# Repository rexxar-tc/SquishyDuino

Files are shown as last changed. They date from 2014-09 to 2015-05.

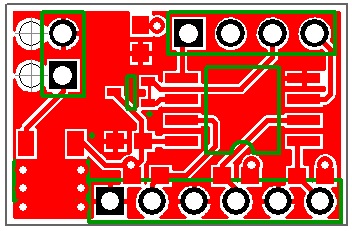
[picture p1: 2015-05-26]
Hardware/PCB_Top.jpg

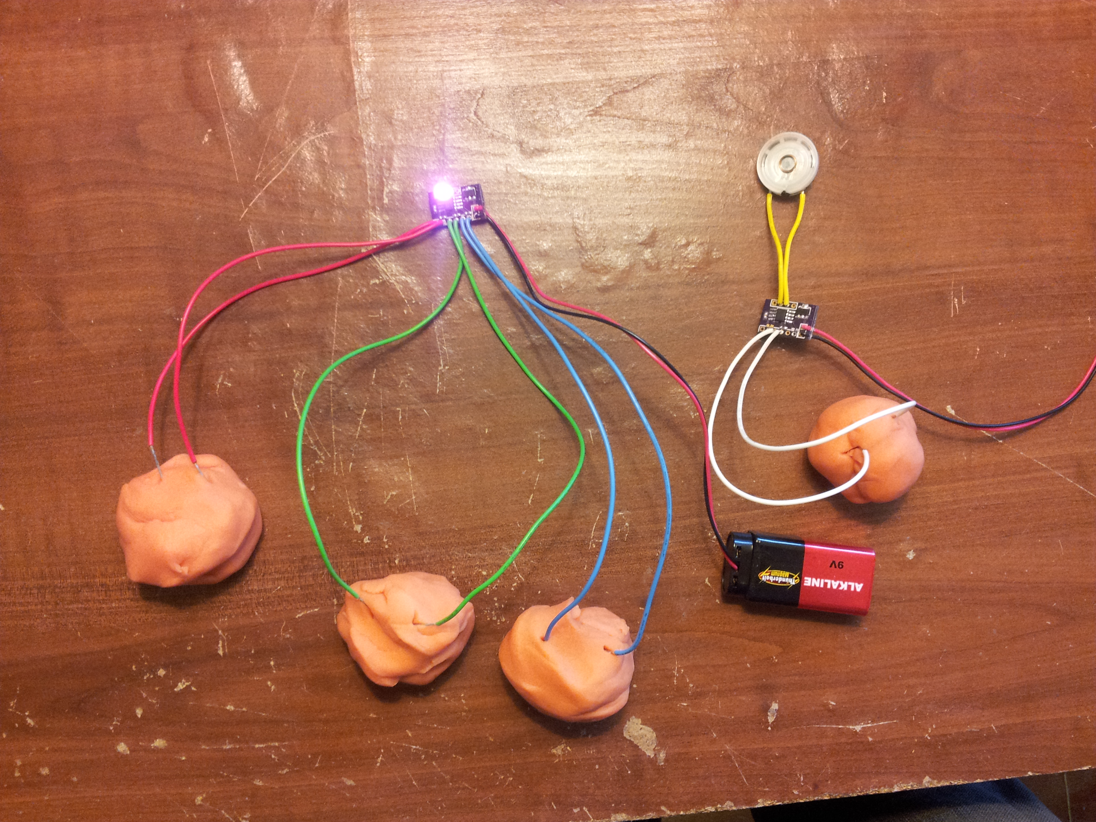
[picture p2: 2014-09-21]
SquishyDuino.jpg

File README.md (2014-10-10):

SquishyDuino
============

##About SquishyDuino

This project came about as part of a children's program at my public library with [Squishy Circuits](http://squishycircuitsstore.com). The hardware is as small and cheap as reasonably possible, and so far has survived abuse by groups of 30+ 8-10 year olds.

The code is inspired by code from St. Thomas University, who created Squishy Circuts. We had to completely re-write it for the ATtiny, but they still get credit for the idea.

The ATtiny25 is not *oficially* supported by Arduino, but we used the [arduino-tiny](https://code.google.com/p/arduino-tiny/) core which worked pretty well.

Essentially, Squishy Circuits is a type of play-dough that has reasonably good conductivity. You can stick an ADC across a lump of dough, and the read voltage will change as the kids play with the dough. Here, we used the ADC values to vary the tone of a speaker, or the individual colors of an RGB LED.

##Tindie Store

SquishyDuino is now available on my [tindie store!](https://www.tindie.com/stores/rexxar/)

Rev2 addresses a problem I didn't expect in the original design; The ATtiny can't source much current, so the speaker was very, very quiet. I fixed that, and updated the code to make it sound better.

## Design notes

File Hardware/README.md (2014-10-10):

##Hardware
==========

The hardware is very simple, but it does use small 0603 surface mount parts, so it will take at least a good temperature-controlled soldering iron to put together.

###Bill of Materials

This is a very short list:

- ATTiny25 in SO-8 package
- 1 1 uf ceramic capacitor in 0603 package
- 1 L7805 5V regulator in SOT89 package
- 1 9V battery clip
- Several pieces of wire

In addition, the LED version requires
- 4 470 ohm resistors in 0603 package
- 1 Common-cathode RGB LED

The buzzer version requires
- 1 small mylar speaker
- 1 220 and 1 470 ohm resistors
- 1 BC846 NPN transistor in SOT-323 package

I recommend [Mouser.com](http://mouser.com) or [Digikey.com](digikey.com) for sourcing these parts.

###PCB

I develop in DipTrace, so I've uploaded both the .dip and gerber files for you to make your own boards, and the boards are also available at [OSHPark](https://oshpark.com/shared_projects/PD8c1KSo) ready to order. 

##Assembly

Assembly requires you be familiar with surface-mount soldering techniques.

The transistor is used as a crude amplifier for the buzzer version, and should not be placed for the LED version. There is a small trace bridging two of the pads of the transistor. If you're building the buzzer version, cut this trace with a razor. For the buzzer, you need to place a 220 ohm resistor in the spot above the transistor, and a 470 ohm resistor on the center placement on the input row. You only need to place wires on the center two pins of the input row, and the speaker goes on the center two pins on the output.

For the LED, leave the bridging trace alone, and don't populate the transistor, then place 470 ohm resistors everywhere else. The LED pinout should be red, ground, green, blue, from left to right. The input wires follow the same order.

Before assembly, make sure to read the Software documentation, as programming the chip is not entirely straightforward.

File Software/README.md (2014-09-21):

##Software
==========

Here's both the Arduino files and pre-compiled hex files ready for uploading. You will need some type of ISP programmer to upload the code. I use an Arduino Leonardo as a programmer. It's easiest to do this with the ATTiny on the board, with only the capacitor and voltage regulator.

The programming pins are

- RESET - 1
- MOSI  - 5
- MISO  - 6
- SCK   - 7

You also need to program the fuses to disable the reset line, as it's used as one of the ADC inputs.

Fuses should be set to

- Low      0xE2
- High	   0x77
- Extended 0xFF

If for some reason you need to reprogram, you'll have to remove the ATTiny and use a high-voltage serial programmer.

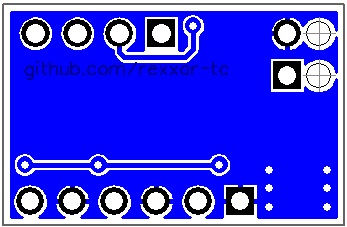
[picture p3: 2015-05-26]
Hardware/PCB_Bottom.jpg

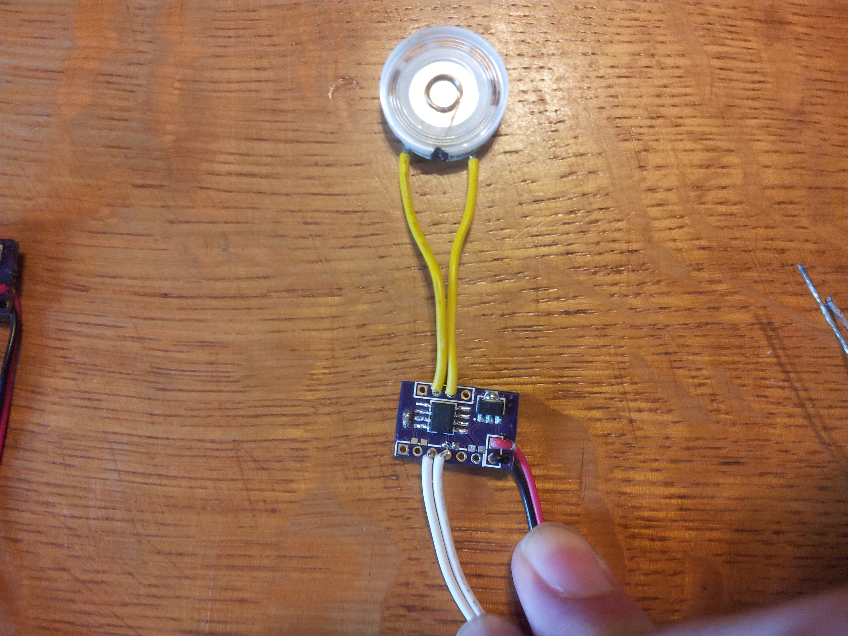
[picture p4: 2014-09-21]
Squishy_Buzzer.jpg

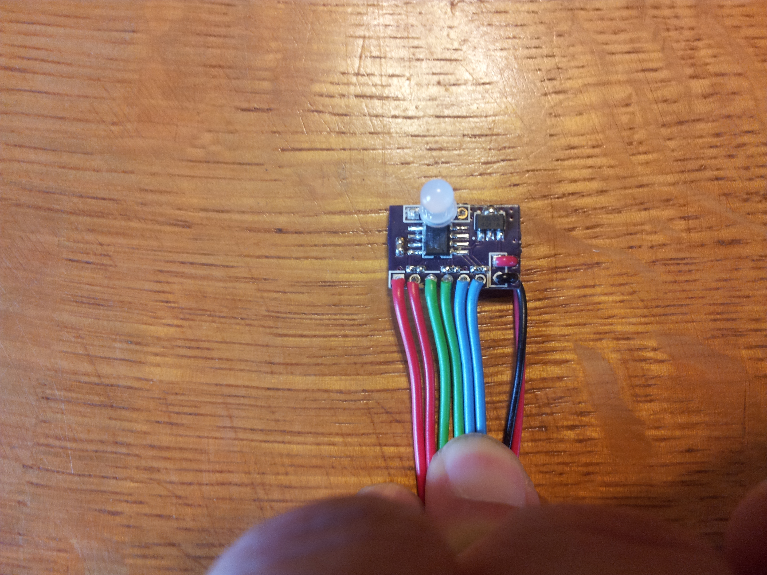
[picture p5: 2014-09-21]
Squishy_RGB.jpg

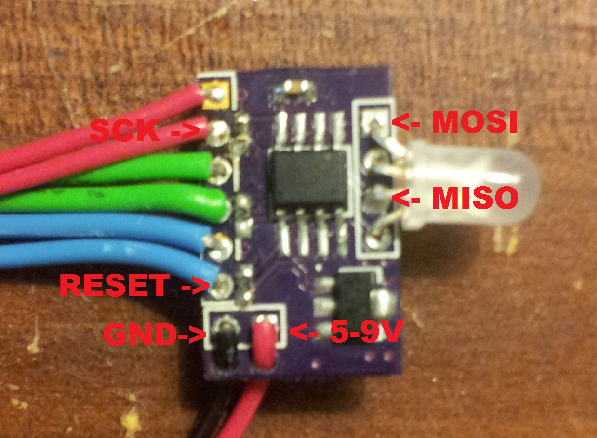
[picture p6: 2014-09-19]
Software/SPI pins.png

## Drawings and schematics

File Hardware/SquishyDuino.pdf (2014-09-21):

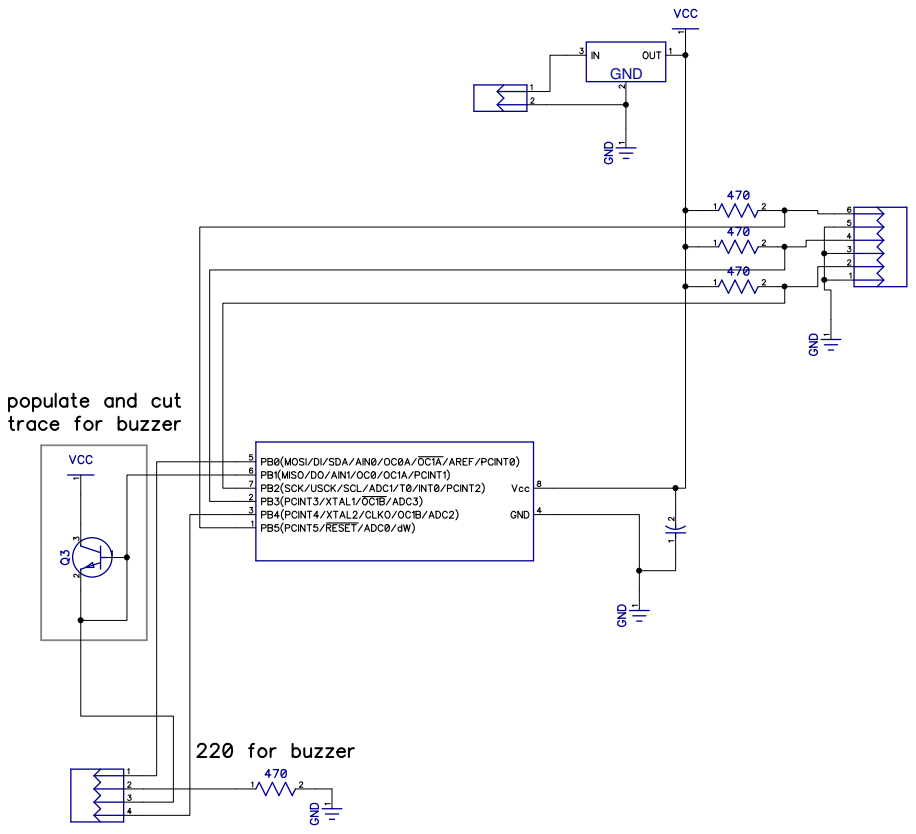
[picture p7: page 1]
GND

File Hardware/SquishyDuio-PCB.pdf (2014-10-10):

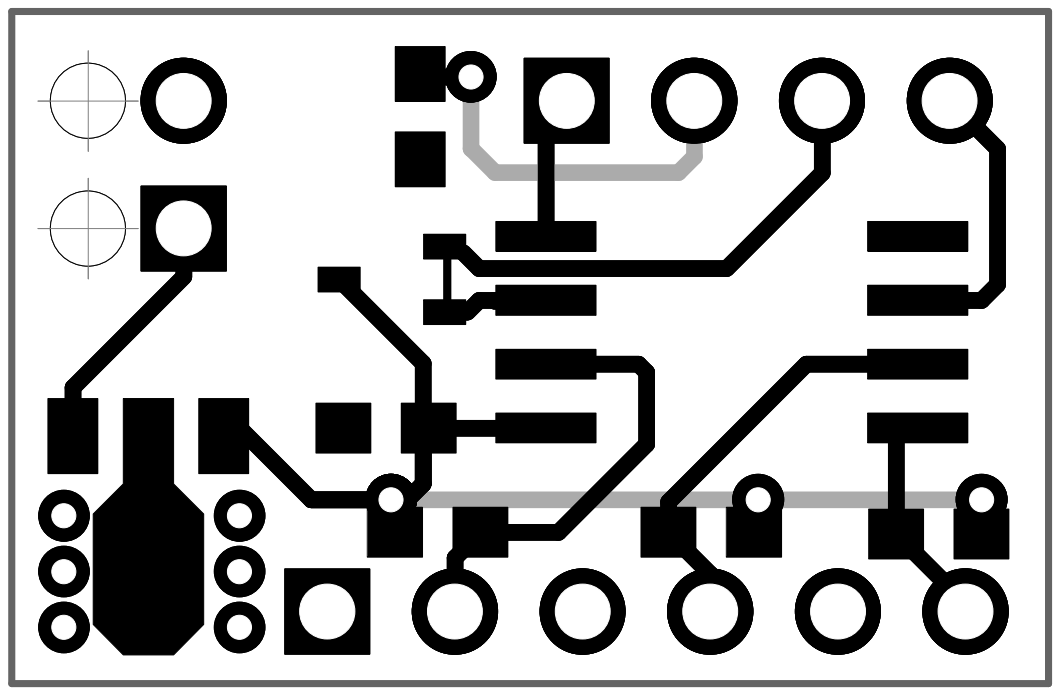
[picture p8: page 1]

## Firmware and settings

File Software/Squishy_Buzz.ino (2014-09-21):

//Original Squishy Sound Code written by Sam Johnson and Modified by Matthew Schmidtbauer for the Squishy Circuits Project
//Rewritten for ATTiny25 SquishyDuino by Brant Martin

//Pin Definitions
#define ADC         3
#define Speaker     1

void setup(){}

void loop()
{
  int raw = 0;
  int frequency = 0;

  for( int i = 0; i < 5; i++)   //sum 5 readings
  {
    raw += analogRead(ADC);     //average measurement out over 10ms to keep the tone
    delay(2);                   //from fluctuating too much between each loop
  }

  if( raw < 200 )               //make sure value doesn't go out of bounds, this can crash the program
    raw = 200;

  else                          //if range is acceptable, divide by 5 to get average
    raw /= 5;

  frequency = raw / 2;          //divide by 2, to get a range between 100 and 512Hz, roughly A2 to B5
  tone( Speaker, frequency );   //play the tone on the speaker
  delay(20);                    //play tone for 20ms, the ATtiny requires this
}

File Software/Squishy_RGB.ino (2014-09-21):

//Original Squishy RGB LED Controller-Code written by Matthew Schmidt Bauer for the Squishy Circuits Project with Annmarie Thomas
//Rewritten for ATTiny25 SquishyDuino by Brant Martin & Chris Easton

//Port Definitions and Variable Declarations:
#define RED_LED 0
#define GREEN_LED 1
#define BLUE_LED 4
#define ANALOG_RED 1
#define ANALOG_GREEN 3
#define ANALOG_BLUE 0

void setup()
{
//Set LED pins to output
pinMode (RED_LED, OUTPUT);
pinMode (GREEN_LED, OUTPUT);
pinMode (BLUE_LED, OUTPUT);
}
void loop()
{ //Read Voltages over Dough:
int raw_RED   = analogRead( ANALOG_RED   );
int raw_GREEN = analogRead( ANALOG_GREEN );
int raw_BLUE  = analogRead( ANALOG_BLUE  );

//Store values in arrays
int raw[3] = { raw_RED, raw_GREEN, raw_BLUE };
int led[3] = { RED_LED, GREEN_LED, BLUE_LED };
int bri[3];

//Normalize ADC values
for ( int i=0; i<3; ++i )
{
    if ( raw[i] >= 500 )
    {
        bri[i] = 0;
    }
    else
    {
        if ( raw[i] <= 150 )
        {
            bri[i] = 2550;
        }
        else
        {
            bri[i] = 3644 - 7*raw[i];
        }
    }
    //Divide final value and write it to LED
    //Divide red value by 15, others by 10, to compensate for red LED's lower forward voltage
    analogWrite ( led[i], 255 - bri[i]/(i==0 ? 15 : 10 ) );
}

}

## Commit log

2014-09-21 Introduced Rev2
    Updated all documentation as necessary
    [SquishyDuino.gbl, SquishyDuino.gbo, SquishyDuino.gbs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]
2015-05-26 Added PCB images
